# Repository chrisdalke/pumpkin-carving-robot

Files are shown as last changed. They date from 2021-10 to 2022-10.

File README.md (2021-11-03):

# Pumpkin Carving Robot

A robot that carves pumpkins! This robot is a Grbl-based CNC machine that uses a rotary table mechanism to cut patterns in pumpkins. It was built in October 2021 by [Andrew Gutierrez](http://andrewtgutierrez.com/) and [Chris Dalke](https://www.chrisdalke.com/). Results ranged from hilariously bad to pretty cool!

This repository holds the Solidworks CAD files for the machine, and python scripts to generate the GCode from an input image. We built this project in a rush as a one-off build, so this project is far from reproducable, but all the files are here.
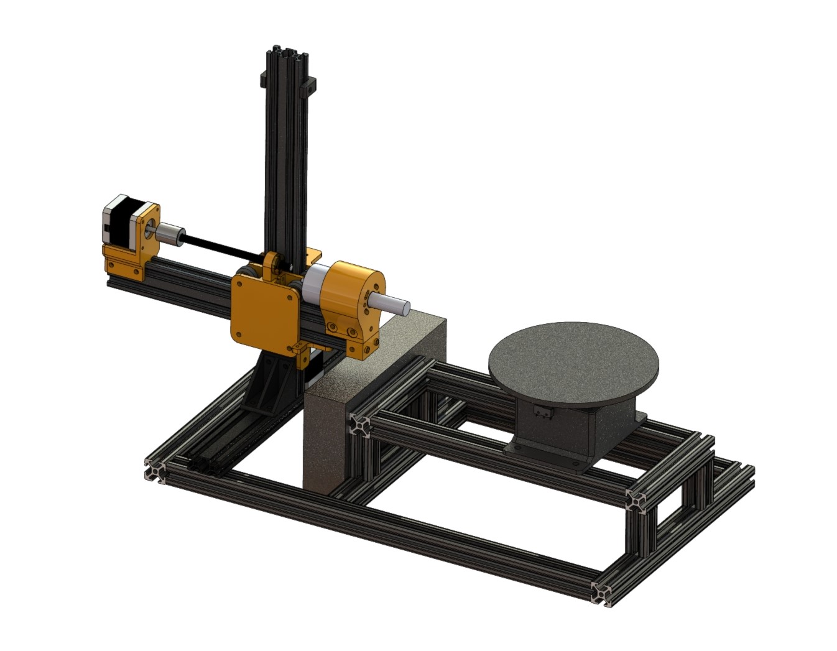
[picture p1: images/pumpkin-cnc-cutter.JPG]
Pumpkin CNC Cutter

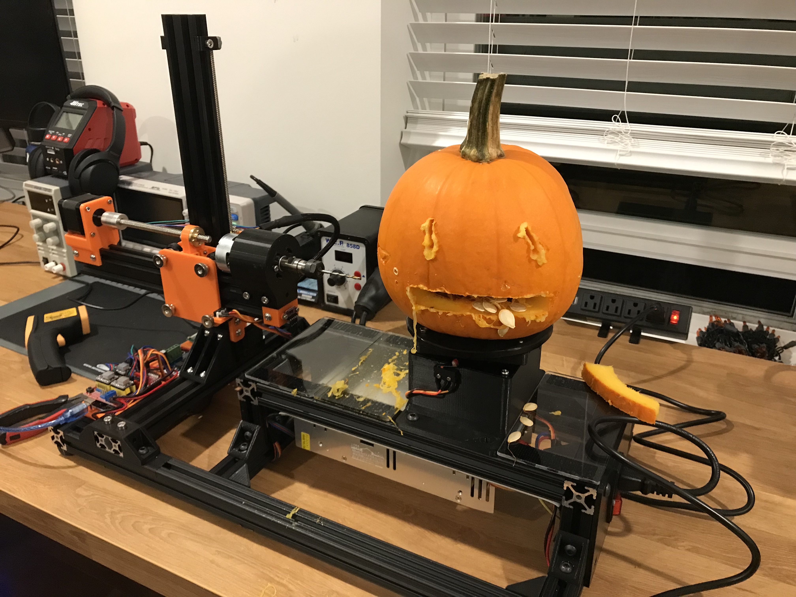
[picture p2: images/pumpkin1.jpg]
Pumpkin 1

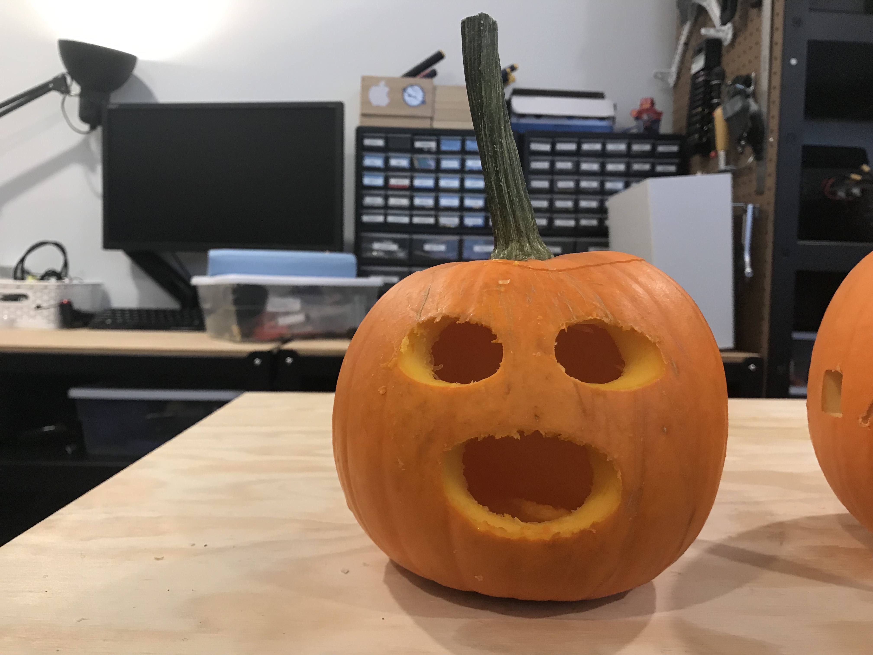
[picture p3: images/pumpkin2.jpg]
Pumpkin 2


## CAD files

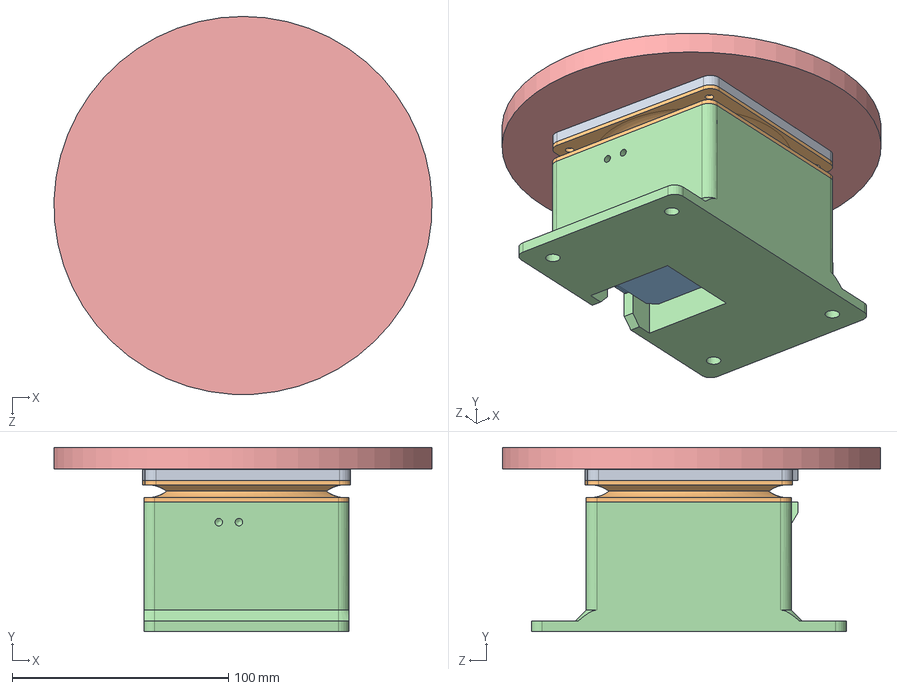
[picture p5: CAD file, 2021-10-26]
hardware/turntable.SLDASM
174.9 x 85.3 x 175.0 mm
Swivel gear mount
Swivel mockup x 2
Nema_17.ipt
Turntable base

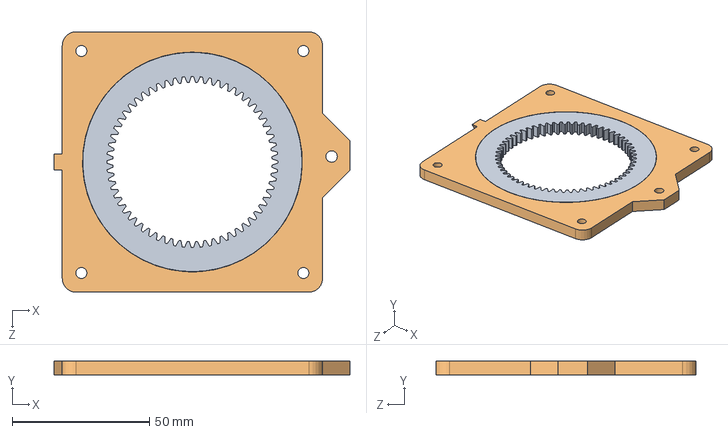
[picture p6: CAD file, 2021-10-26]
hardware/turntable gear combined.SLDASM
108.0 x 5.00 x 95.0 mm
internal spur gear_am
swivel nail mount

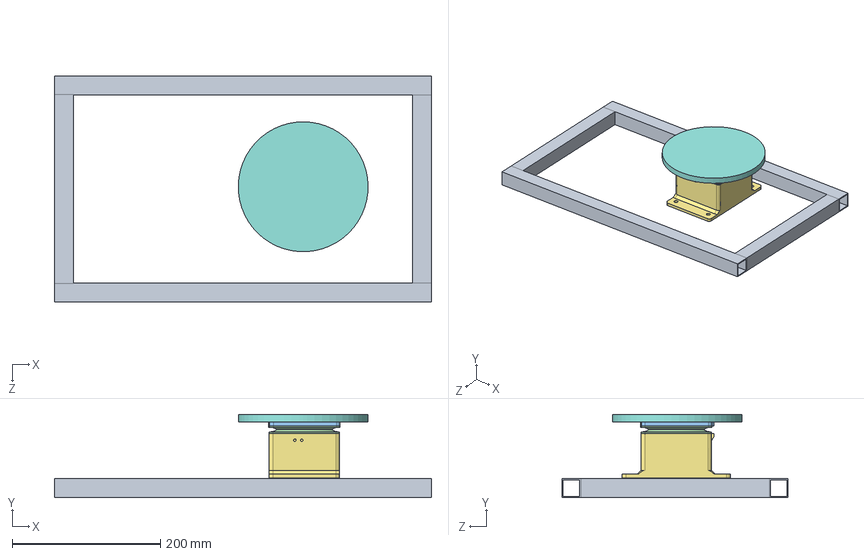
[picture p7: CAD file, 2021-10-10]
hardware/assembly.SLDASM
508.0 x 111.8 x 304.8 mm
tube square_aai x 4
internal spur gear_am
Swivel gear mount
Swivel mockup x 2
Nema_17.ipt
spur gear_am
Turntable base

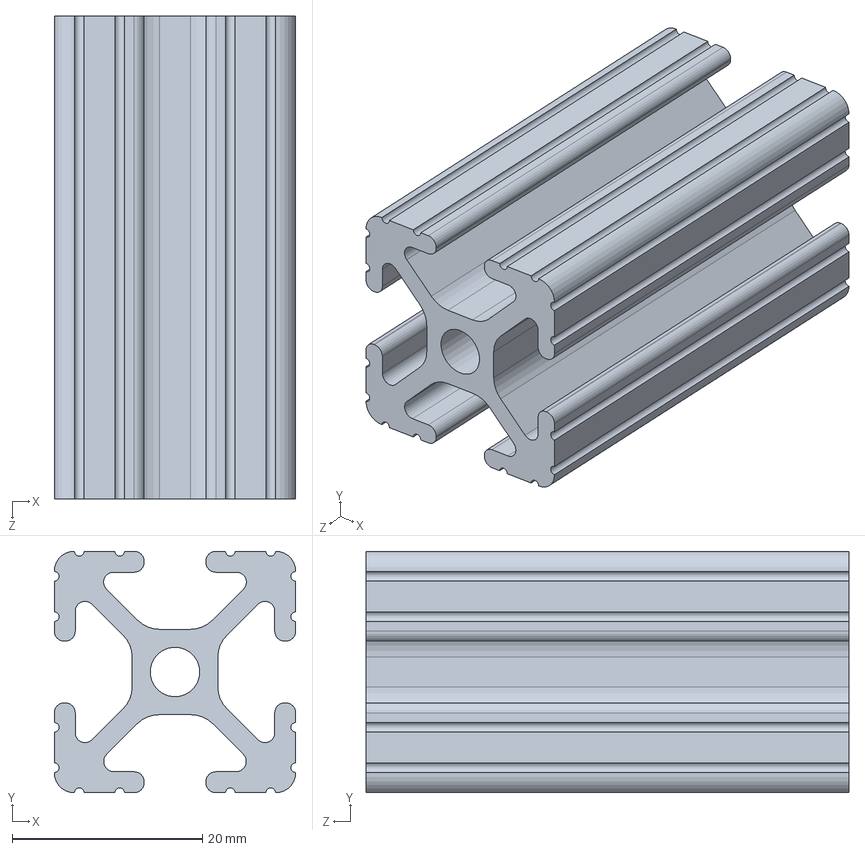
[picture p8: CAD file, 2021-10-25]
hardware/8020/8020-1010-BLACK X 2.SLDPRT
25.4 x 25.4 x 50.8 mm

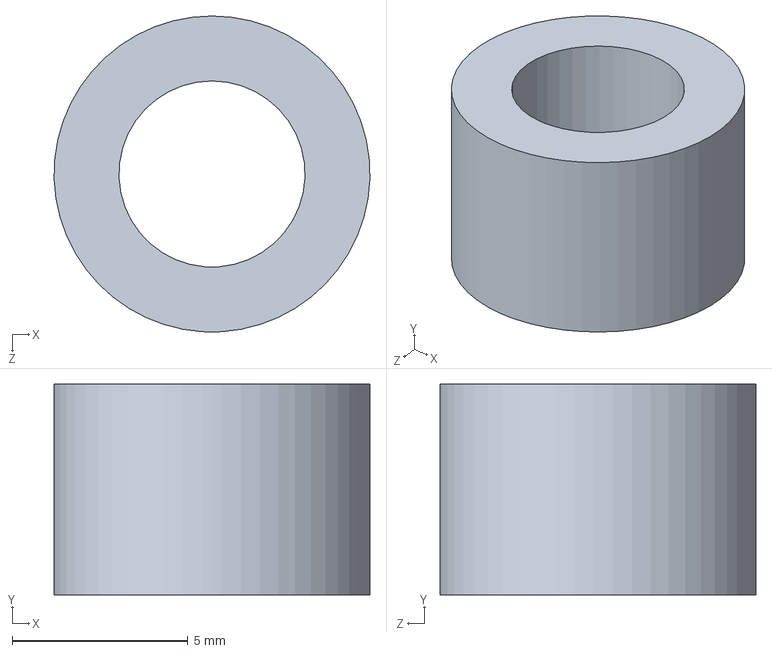
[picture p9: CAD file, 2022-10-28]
hardware/z_spacer_6mm.SLDPRT
9.00 x 6.00 x 9.00 mm

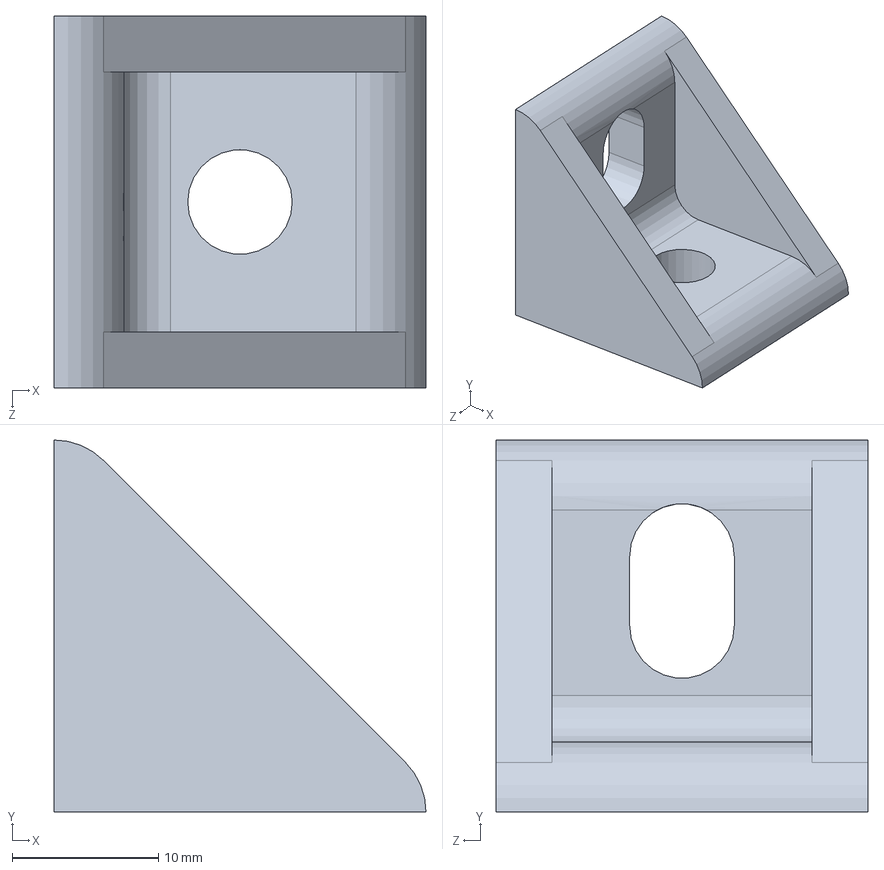
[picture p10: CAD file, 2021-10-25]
hardware/8020/8020-4265-BLACK.SLDPRT
25.4 x 25.4 x 25.4 mm

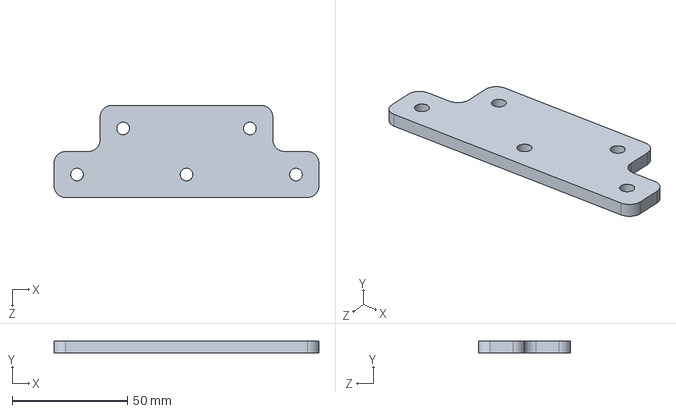
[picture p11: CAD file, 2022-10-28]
hardware/z_axis_bracket_front.SLDPRT
115.0 x 5.00 x 40.0 mm

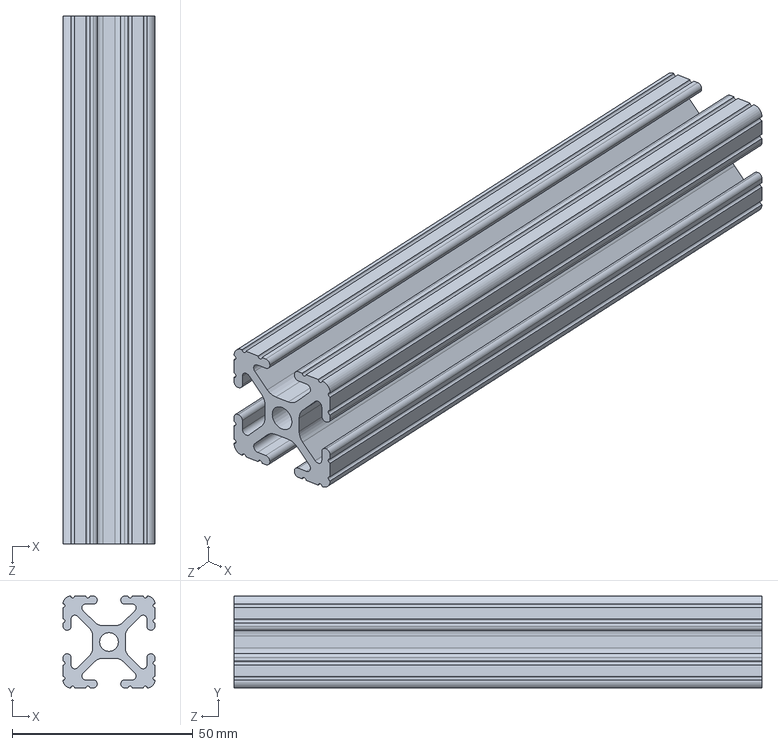
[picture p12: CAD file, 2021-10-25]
hardware/8020/8020-1010-BLACK X 5_75.SLDPRT
25.4 x 25.4 x 146.1 mm

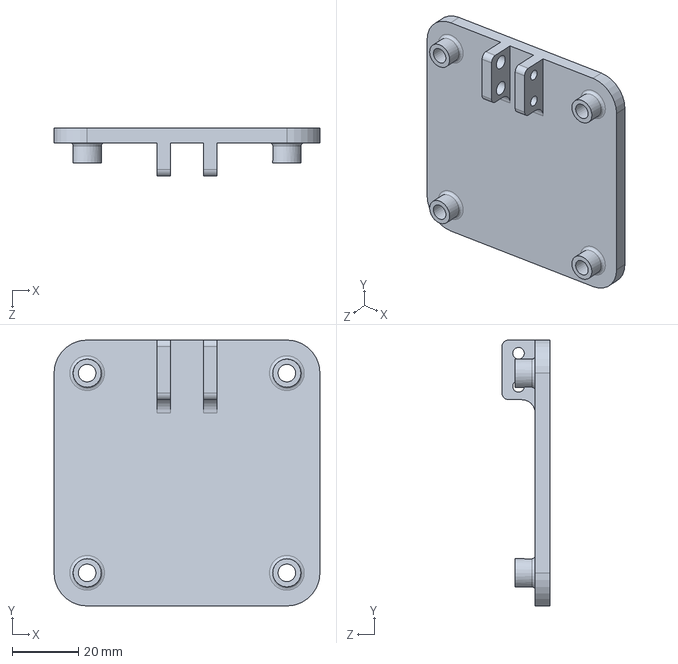
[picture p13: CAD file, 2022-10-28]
hardware/z_carriage_middle.SLDPRT
80.2 x 80.2 x 14.5 mm

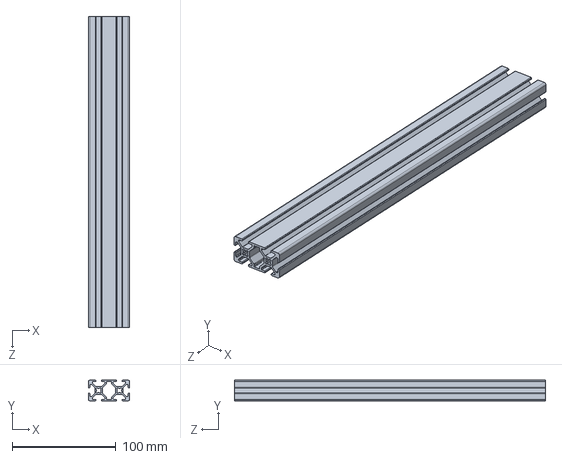
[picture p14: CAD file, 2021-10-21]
hardware/8020/8020-20-2040-BLACK.SLDPRT
40.0 x 20.0 x 300.0 mm

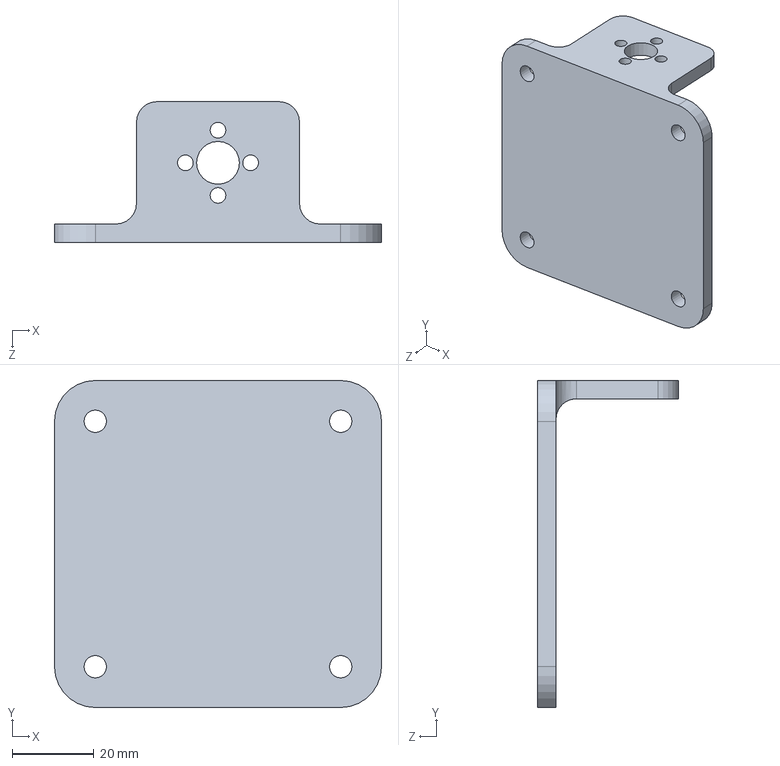
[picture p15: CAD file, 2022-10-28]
hardware/z_carriage_bottom.SLDPRT
80.2 x 80.2 x 34.5 mm

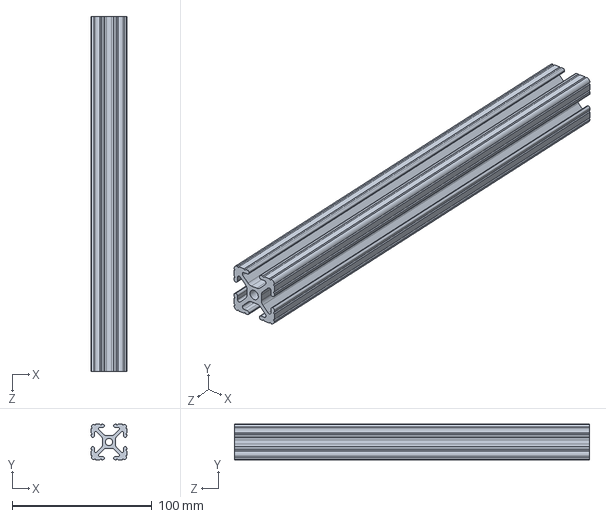
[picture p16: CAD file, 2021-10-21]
hardware/8020/8020-1010-BLACK X 10.SLDPRT
25.4 x 25.4 x 254.0 mm

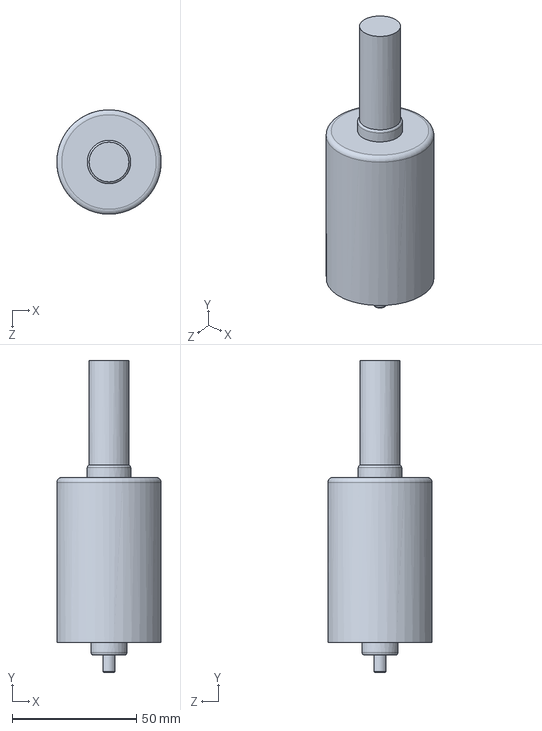
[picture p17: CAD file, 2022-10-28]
hardware/spindle.SLDPRT
42.0 x 125.5 x 42.0 mm

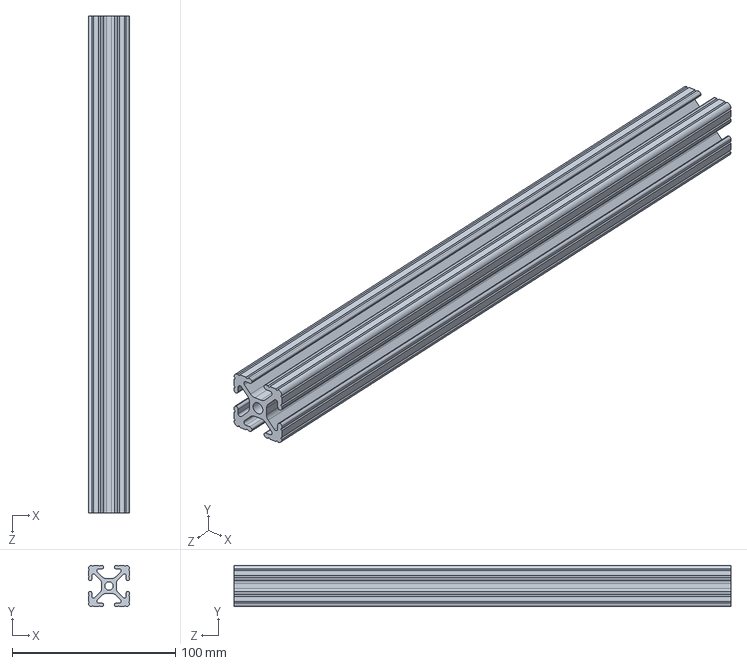
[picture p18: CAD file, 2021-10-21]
hardware/8020/8020-1010-BLACK X 12.SLDPRT
25.4 x 25.4 x 304.8 mm

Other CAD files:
hardware/8020/8020-20-2040 X 0_3048 M.SLDPRT
hardware/z_axis_400mm.SLDPRT
hardware/8020/8020-1010-BLACK X 8.SLDPRT
hardware/v_slot_12in.SLDPRT
hardware/775 Holder v1.SLDPRT
hardware/8020/8020-1010-BLACK X 18.SLDPRT
hardware/8020/8020-1010-BLACK X 20.SLDPRT
hardware/8020/8020-1010-BLACK X 22.SLDPRT
hardware/8020/8020-20-2040 X 0_254 M.SLDPRT
hardware/PSU placeholder.SLDPRT
hardware/Swivel gear mount.SLDPRT
hardware/Swivel mockup.SLDPRT
hardware/Turntable base.SLDPRT
hardware/calibrator_mount.SLDPRT
hardware/coupler.SLDPRT
hardware/driver_mount.SLDPRT
hardware/electronics_mount.SLDPRT
hardware/foot.SLDPRT
hardware/gantry_300mm.SLDPRT
hardware/gantry_anchor.SLDPRT
hardware/gantry_stepper_bracket.SLDPRT
hardware/internal spur gear_am 3.SLDPRT
hardware/lead_screw_nut.SLDPRT
hardware/legacy/z_carriage_left.SLDPRT
hardware/metric-to-imperial 8020 mount.SLDPRT
hardware/power plug panel.SLDPRT
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

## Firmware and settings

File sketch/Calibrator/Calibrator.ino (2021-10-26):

#include <Wire.h>
#include <VL53L0X.h>

VL53L0X sensor;

void setup()
{
  Serial.begin(115200);
  
  // Configure Sensor
  Wire.begin();
  sensor.setTimeout(500);
  while (!sensor.init())
  {
    Serial.println("Failed to detect and initialize sensor!");
    delay(1000);
  }
  sensor.setMeasurementTimingBudget(200000);
}

void loop()
{ 
  if( Serial.available() > 0 )
  {
    byte inByte = Serial.read();
    if (true)
    {
      // Poll sensor
      uint16_t reading = sense(10);

      // Pack data
      uint8_t packet[3];
      packet[0] = 0x0F;
      packet[1] = (reading & 0xFF00) >> 8;
      packet[2] = (reading & 0x00FF);

      // Write data
      for (uint8_t i=0; i<3; i++)
      {
        Serial.write(packet[i]);
      }
    }
  }
}

/*
 * Poll the ToF sensor to get a reading. The reading is an 
 * average over the number of samples specified.
 */
uint16_t sense(byte numSamples)
{
  uint16_t total = 0;

  for (int i=0; i < numSamples; i++)
  {
    total += sensor.readRangeSingleMillimeters();
  }

  return (uint16_t) (total/numSamples);
}

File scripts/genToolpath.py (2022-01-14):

import os
import sys
import csv
import cv2
import argparse
import numpy as np

def main():
    # Determine the correct calibration file to use
    calibration_path = 'calibration.csv'
    bit_offset_mm = 47
    axis_offset = 168

    parser = argparse.ArgumentParser()
    parser.add_argument('-f', '--file', help ='Image file to process')
    parser.add_argument('-c', '--calibrationFile', help ='Use path to supplied calibration file')
    parser.add_argument('-b', '--bitOffset', help ='Offset from the collet to the bit')
    args = parser.parse_args()

    # check for input file
    if args.file:
        if not os.path.exists(args.file): 
            sys.exit('ERROR: Input file %s does not exist' % args.file)
    else:
        sys.exit('ERROR: Input file not provided')
        
    # load in calibration file 
    if args.calibrationFile:
        print('Using calibration file at: %s' % args.calibrationFile)
        calibration_path = args.calibrationFile
    else:
        print('Using default calibration file at: %s' % calibration_path)

    calibration, x_max, x_min = ingest_calibration(calibration_path)
    x_height = x_max - x_min
    print('Calibration loaded sucessfully')

    # update the bit offset if needed
    if args.bitOffset:
        bit_offset_mm = int(args.bitOffset)
        print('Using supplied bit offset of %d' % bit_offset_mm)
    else:
        print('Using default bit offset of %d' % bit_offset_mm)

    # load input image
    img = cv2.imread(args.file)
    IMG_WIDTH = img.shape[1]
    IMG_HEIGHT = img.shape[0]

    # generate the pruned contours
    pruned_contours, contours = detect_contours(img)
    img_cont = draw_pruned_contours(img, pruned_contours, contours)

    # convert paths to pumkin coordinates
    paths = []
    for path in pruned_contours:
        path_mm = []
        for point in path:
            # convert to pumpkin space
            x_mm = ((IMG_HEIGHT - point[1]) * (x_height/IMG_HEIGHT)) + x_min
            y_mm = (IMG_WIDTH - point[0]) / (IMG_WIDTH/360)
            path_mm.append([x_mm, y_mm, 0]) 
        path_mm.append(path_mm[0]) # close the loop
        paths.append(path_mm)
    
    # generate toolpath from paths
    toolpath = generate_gcode(paths, calibration, bit_offset_mm, axis_offset)
    #TODO: use the name of the input file for the gcode
    
    # write gcode to file
    gcode_filename = 'output.gcode'
    f = open(gcode_filename, 'w')
    for line in toolpath:
        f.write(line)
    f.close()

    # show image
    cv2.imshow('Detected contours', img_cont)
    while True:
        if cv2.waitKey(33) == ord('q'):
            sys.exit('Closing...')

def ingest_calibration(filename):
    # TODO: return full calibration array with interpolated points
    raw = np.genfromtxt(filename, delimiter=',')
    
    # convert to mm/deg
    x_max = raw.max(axis=0)[0]
    x_min = raw.min(axis=0)[0]
    cal = np.full(shape = (int(x_max - x_min) + 1, 360), fill_value=-1 )

    for point in raw:
        cal[int(point[0] - x_min), int(point[1])] = point[2]
        # TODO: Fill out interpolated points 

    return raw, x_max, x_min

def detect_contours(img):
    # color transform
    gray = cv2.cvtColor(img, cv2.COLOR_BGR2GRAY)
    ret, thresh = cv2.threshold(gray, 150, 255, cv2.THRESH_BINARY_INV)

    # detect contours
    contours, hierarchy = cv2.findContours(image=thresh, mode=cv2.RETR_EXTERNAL, method=cv2.CHAIN_APPROX_SIMPLE)
    print('Detected %d contours' % len(contours))

    # Iterate through the contours to prune
    contour_num = 0
    pruned_contours = []
    for contour in contours:
        pruned_contour = contour.copy().squeeze()

        i = 0
        while i < len(pruned_contour) -2:
            p0 = pruned_contour[i]
            p1 = pruned_contour[i+1]
            p2 = pruned_contour[i+2]

            if collinearity_check( p0, p1, p2, 10): 
                pruned_contour = np.delete(pruned_contour, i+1, 0)
            else:
                i += 1

        print('Pruned contour %d from %d points to %d' % (contour_num, len(contour), len(pruned_contour)))
        pruned_contours.append(pruned_contour)
        contour_num += 1

    return pruned_contours, contours

def draw_pruned_contours(img, pruned_contours, contours):
    image_copy = img.copy()
    cv2.drawContours(image=image_copy, contours=contours, contourIdx=-1, color=(0, 255, 0), thickness=1, lineType=cv2.LINE_AA)
    cv2.drawContours(image=image_copy, contours=pruned_contours, contourIdx=-1, color=(255, 0, 0), thickness=1, lineType=cv2.LINE_AA)

    # interate through and draw the pruned verticies in red
    for contour in pruned_contours:
        for point in contour:
            cv2.circle( image_copy, (point[0], point[1]), 2, (0,0,255), 1)

    return image_copy

def collinearity_check(p0, p1, p2, epsilon = 1e-3):
    p0_ = np.insert(p0, 0, 1, axis =0)
    p1_ = np.insert(p1, 0, 1, axis =0)
    p2_ = np.insert(p2, 0, 1, axis =0)

    m = np.stack((p0_, p1_, p2_), 0)
    det = np.linalg.det(m)

    return abs(det) < epsilon
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

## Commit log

2021-10-10 First pass at z-axis hardware
    [z_axis_400mm.SLDPRT, z_bearing_bracket.SLDPRT, z_motor_bracket.SLDPRT]
2021-10-10 Working on turntable assembly, pulled in third-party NEMA 17 stepper and RPI 3
    [Swivel gear mount.SLDPRT, Swivel mockup.SLDPRT, Turntable base.SLDPRT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]
2021-10-17 Added z-axis carriage + started gantry
    [gantry_300mm.SLDPRT, roller.SLDPRT, z_bearing_bracket.SLDPRT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]
2021-10-18 Completed gantry parts and added to assembly
    [coupler.SLDPRT, gantry_anchor.SLDPRT, gantry_stepper_bracket.SLDPRT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]
2021-10-18 Update spur gear sizing, add spacer for NEMA stepper
    [spacer.SLDPRT, stepper spur gear.SLDPRT]
2021-10-18 Add 775 holder
    [775 Holder v1.SLDPRT]
2021-10-21 Added limit switches and ToF mount
    [775 Holder v1.SLDPRT, gantry_300mm.SLDPRT, spindle.SLDPRT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]
2021-10-21 Add 8020 hardware and complete assembly
    [8020-1010-BLACK X 10.SLDPRT, 8020-1010-BLACK X 12.SLDPRT, 8020-1010-BLACK X 18.SLDPRT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]
2021-10-25 Finish assembly, add power plug panel, add 8020 mounts
    [8020-1010-BLACK X 2.SLDPRT, 8020-1010-BLACK X 5_75.SLDPRT, 8020-4265-BLACK.SLDPRT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]
2021-10-25 First cut at ToF calibration sketch
2021-10-26 Prototyping mounts for PSU, power plug, turntable zero
    [Swivel gear mount.SLDPRT, psu mount.SLDPRT, swivel nail mount.SLDPRT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]
2021-10-26 First pass at grbl control, ToF polling and a simple calibration routine
2021-10-30 fully functional calibration script + visualizer
2021-11-03 Add CAD image to readme
2021-11-03 Add pumpkin screenshots
2022-10-28 Dual z-axis mod
    [775 Holder v1.SLDPRT, calibrator_mount.SLDPRT, coupler.SLDPRT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]
